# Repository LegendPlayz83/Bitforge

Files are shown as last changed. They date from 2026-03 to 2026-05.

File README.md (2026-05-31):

# Bitforge



Online view:


Features:

- 81x Diodes
- 81x keys
- Raspberry Pi Pico
- Customised layout
- QMK firmware
  
### Schematic


### PCB 


### Case


### BOM

| Name | Quantity | Cost | Link |
|---|---|---|---|
| TTC Silent Red V3 | 81 | $44.99 | [Buy](https://stackskb.com/store/ttc-silent-red-v3-switch/) |
| Durock Smokey Screw-In Stabilizers V2 (4+1 w/ 6.25u spacebar) | 1 | $17.01 | [Buy](https://stackskb.com/store/durock-smokey-screw-in-stabilizers-v2/) |
| Womier Azure Eclipse Side Backlit Cherry PBT Keycap | 1 | $26 | [Buy](https://curiositycaps.in/products/flow-backlit-side-printed-cherry-pbt-keycap-set) |
| Diode 1N4148 Through-Hole | 100 | $2.15 | [Buy](https://www.amazon.in/dp/B084ZP5BJ3) |
| PCB - (Black Color) | 5 | $60.00 | [Buy](https://jlcpcb.com/) |
| Raspberry Pi Pico | 1 | $6.40 | [Buy](https://www.amazon.in/Raspberry-Pi-Headers-Soldered-Micro/dp/B08WPNM7JB) |
| Heatset and Screws | 1 | $0.00 | Self-sourced |
| Case (top, mid, bot) | 1 | $0.00 | Printing Legion |
| **Total** | | **$158.99** | |

The total costs come out to be $159

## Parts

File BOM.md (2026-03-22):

### BOM

| Name | Quantity | Cost | Link |
|---|---|---|---|
| TTC Silent Red V3 | 81 | $47 | [Buy](https://stackskb.com/store/ttc-silent-red-v3-switch/) |
| Durock Smokey Screw-In Stabilizers V2 (4+1 w/ 6.25u spacebar) | 1 | $20 | [Buy](https://stackskb.com/store/durock-smokey-screw-in-stabilizers-v2/) |
| Womier Azure Eclipse Side Backlit Cherry PBT Keycap | 1 | $26 | [Buy](https://curiositycaps.in/products/flow-backlit-side-printed-cherry-pbt-keycap-set) |
| Diode 1N4148 Through-Hole | 100 | $2.15 | [Buy](https://www.amazon.in/dp/B084ZP5BJ3) |
| PCB - (Black Color) | 5 | $42.00 | [Buy](https://jlcpcb.com/) |
| Raspberry Pi Pico | 1 | $10 | [Buy](https://www.amazon.in/Raspberry-Pi-Headers-Soldered-Micro/dp/B08WPNM7JB) |
| Heatset and Screws | 1 | $6 | [Buy](https://www.onlyscrews.in)  |
| Case  | 1 | $5.00 | Printing Legion |
| **Total** | | **$158.15** | |

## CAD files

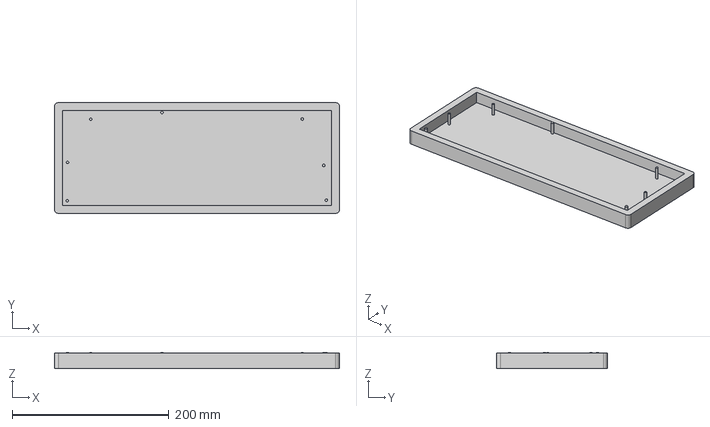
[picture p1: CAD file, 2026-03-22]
CAD/Bitforge-Case.step
363.4 x 141.4 x 20.6 mm

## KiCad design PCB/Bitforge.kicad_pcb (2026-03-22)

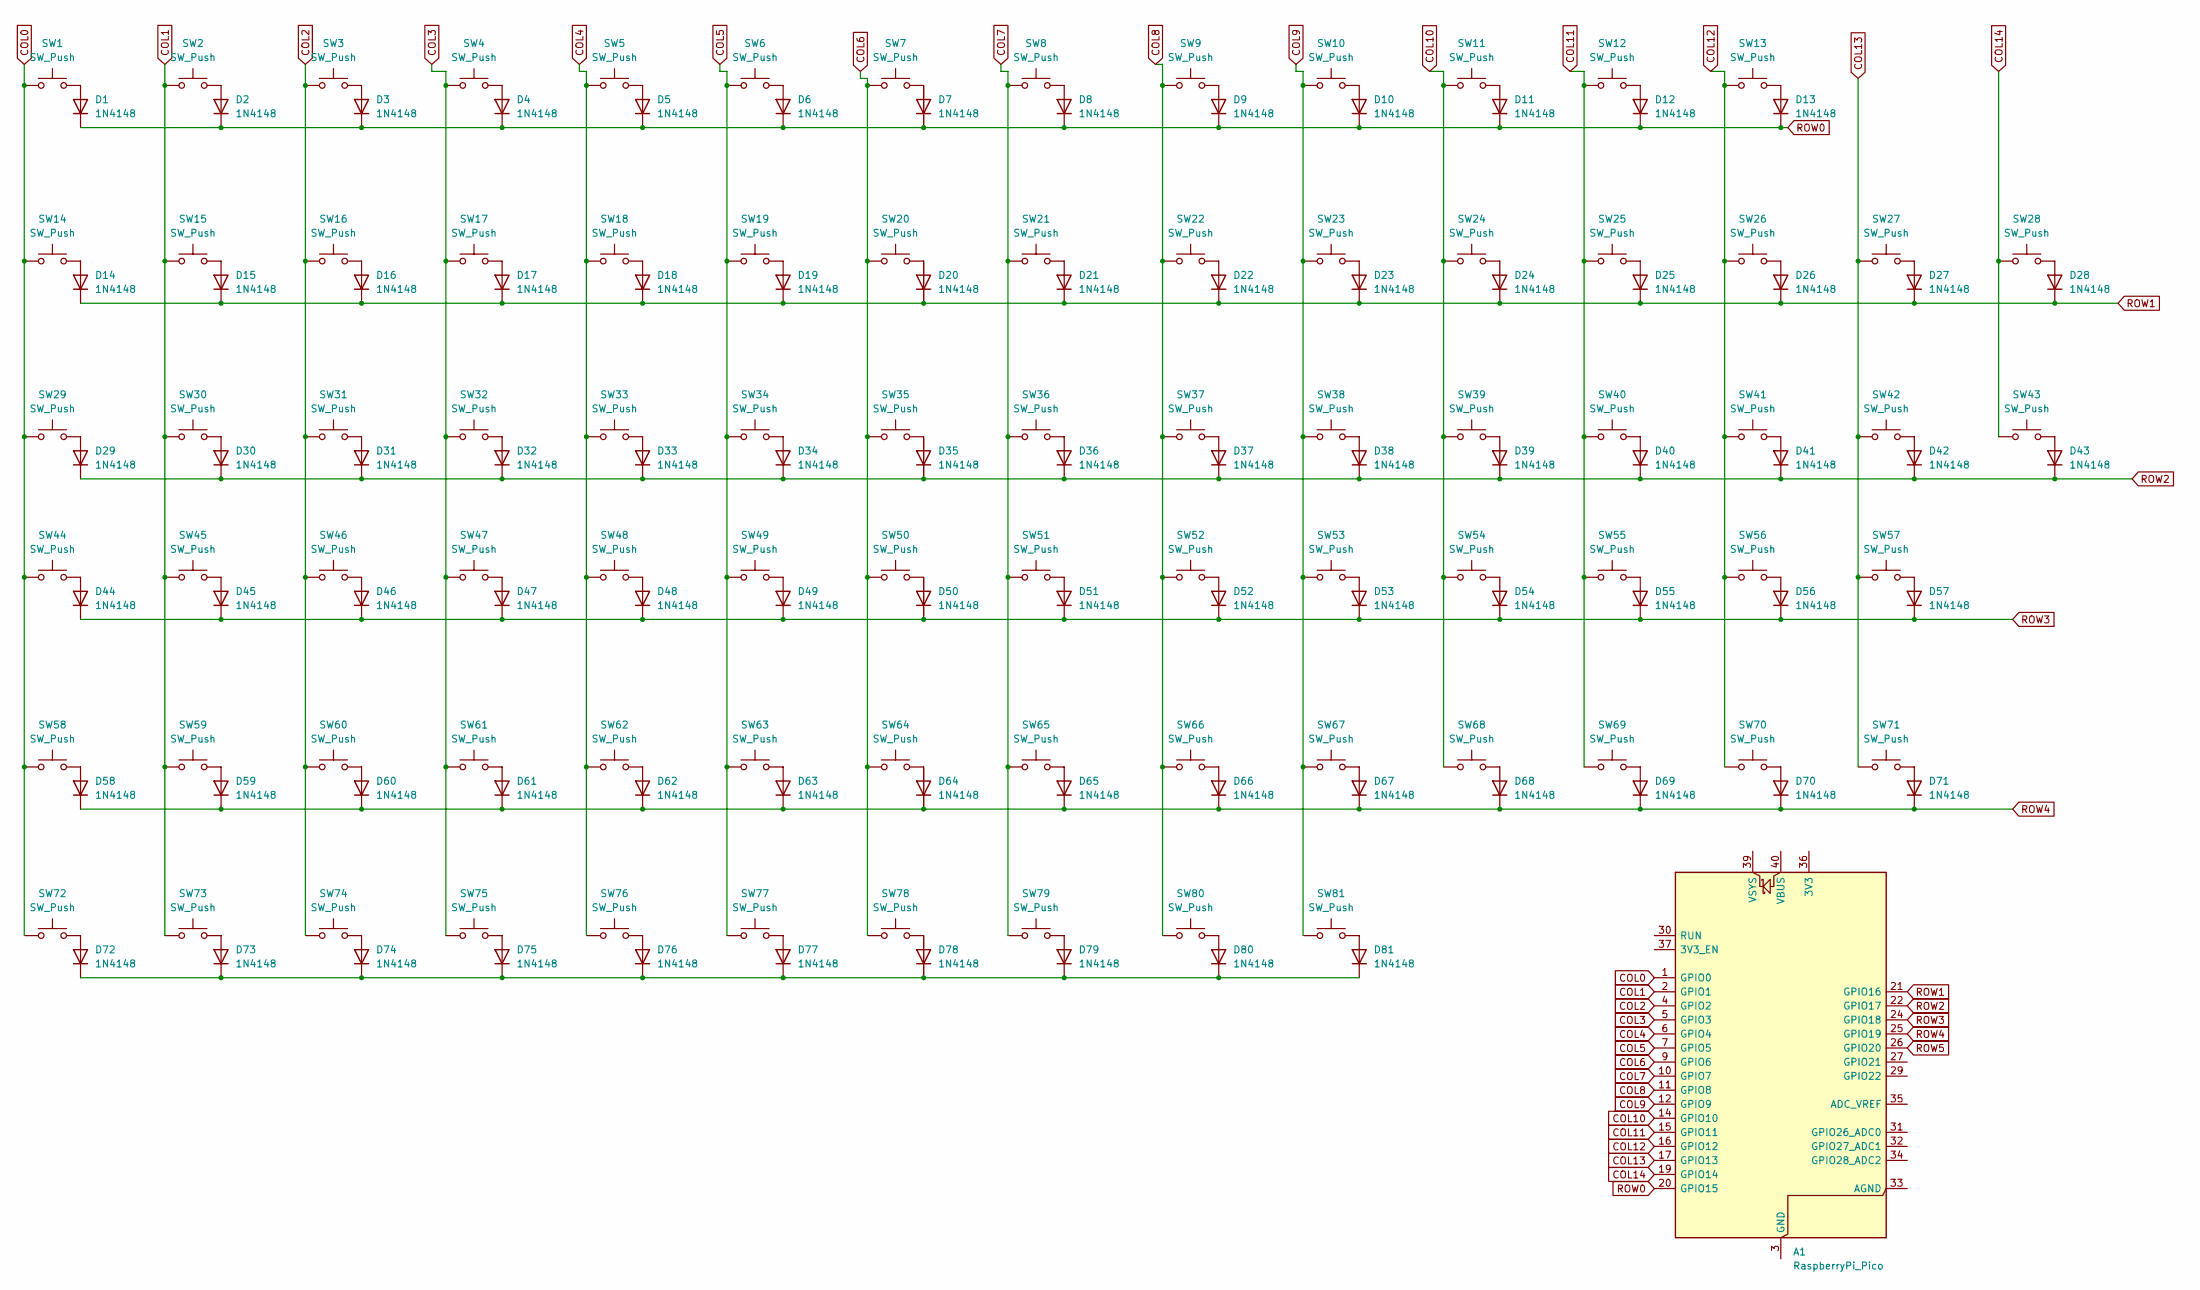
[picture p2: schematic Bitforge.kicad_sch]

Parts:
A1: RaspberryPi_Pico; RaspberryPi_Pico_Common_THT
D1, D2, D3, D4, D5, D6, D7, D8, D9, D10, D11, D12, D13, D14, D15, D16, D17, D18, D19, D20, D21, D22, D23, D24, D25, D26, D27, D28, D29, D30, D31, D32, D33, D34, D35, D36, D37, D38, D39, D40, D41, D42, D43, D44, D45, D46, D47, D48, D49, D50, D51, D52, D53, D54, D55, D56, D57, D58, D59, D60, D61, D62, D63, D64, D65, D66, D67, D68, D69, D70, D71, D72, D73, D74, D75, D76, D77, D78, D79, D80, D81: 1N4148; D_DO-35_SOD27_P7.62mm_Horizontal
SW1, SW2, SW3, SW4, SW5, SW6, SW7, SW8, SW9, SW10, SW11, SW12, SW13, SW14, SW15, SW16, SW17, SW18, SW19, SW20, SW21, SW22, SW23, SW24, SW25, SW26, SW28, SW30, SW31, SW32, SW33, SW34, SW35, SW36, SW37, SW38, SW39, SW40, SW41, SW43, SW45, SW46, SW47, SW48, SW49, SW50, SW51, SW52, SW53, SW54, SW55, SW57, SW59, SW60, SW61, SW62, SW63, SW64, SW65, SW66, SW67, SW68, SW70, SW71, SW76, SW77, SW78, SW79, SW80, SW81: SW_Push; SW_Cherry_MX_1.00u_PCB
SW27: SW_Push; SW_Cherry_MX_2.00u_PCB
SW29: SW_Push; SW_Cherry_MX_1.50u_PCB
SW42, SW72, SW73, SW74: SW_Push; SW_Cherry_MX_1.25u_PCB
SW44, SW69: SW_Push; SW_Cherry_MX_1.75u_PCB
SW56, SW58: SW_Push; SW_Cherry_MX_2.25u_PCB
SW75: SW_Push; SW_Cherry_MX_6.25u_PCB

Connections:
COL0: A1.1 (GPIO0), SW1.1, SW14.1, SW29.1, SW44.1, SW58.1, SW72.1
COL1: A1.2 (GPIO1), SW2.1, SW15.1, SW30.1, SW45.1, SW59.1, SW73.1
COL2: A1.4 (GPIO2), SW3.1, SW16.1, SW31.1, SW46.1, SW60.1, SW74.1
COL3: A1.5 (GPIO3), SW4.1, SW17.1, SW32.1, SW47.1, SW61.1, SW75.1
COL4: A1.6 (GPIO4), SW5.1, SW18.1, SW33.1, SW48.1, SW62.1, SW76.1
COL5: A1.7 (GPIO5), SW6.1, SW19.1, SW34.1, SW49.1, SW63.1, SW77.1
COL6: A1.9 (GPIO6), SW7.1, SW20.1, SW35.1, SW50.1, SW64.1, SW78.1
COL7: A1.10 (GPIO7), SW8.1, SW21.1, SW36.1, SW51.1, SW65.1, SW79.1
COL8: A1.11 (GPIO8), SW9.1, SW22.1, SW37.1, SW52.1, SW66.1, SW80.1
COL9: A1.12 (GPIO9), SW10.1, SW23.1, SW38.1, SW53.1, SW67.1, SW81.1
COL10: A1.14 (GPIO10), SW11.1, SW24.1, SW39.1, SW54.1, SW68.1
COL11: A1.15 (GPIO11), SW12.1, SW25.1, SW40.1, SW55.1, SW69.1
COL12: A1.16 (GPIO12), SW13.1, SW26.1, SW41.1, SW56.1, SW70.1
COL13: A1.17 (GPIO13), SW27.1, SW42.1, SW57.1, SW71.1
COL14: A1.19 (GPIO14), SW28.1, SW43.1
unnamed: A1.3 (GND), A1.8 (GND), A1.13 (GND), A1.18 (GND), A1.23 (GND), A1.28 (GND), A1.38 (GND)
unnamed: D1.2 (A), SW1.2
unnamed: D2.2 (A), SW2.2
unnamed: D3.2 (A), SW3.2
unnamed: D4.2 (A), SW4.2
unnamed: D5.2 (A), SW5.2
unnamed: D6.2 (A), SW6.2
unnamed: D7.2 (A), SW7.2
unnamed: D8.2 (A), SW8.2
unnamed: D9.2 (A), SW9.2
unnamed: D10.2 (A), SW10.2
unnamed: D11.2 (A), SW11.2
unnamed: D12.2 (A), SW12.2
unnamed: D13.2 (A), SW13.2
unnamed: D14.2 (A), SW14.2
unnamed: D15.2 (A), SW15.2
unnamed: D16.2 (A), SW16.2
unnamed: D17.2 (A), SW17.2
unnamed: D18.2 (A), SW18.2
unnamed: D19.2 (A), SW19.2
unnamed: D20.2 (A), SW20.2
unnamed: D21.2 (A), SW21.2
unnamed: D22.2 (A), SW22.2
unnamed: D23.2 (A), SW23.2
unnamed: D24.2 (A), SW24.2
unnamed: D25.2 (A), SW25.2
unnamed: D26.2 (A), SW26.2
unnamed: D27.2 (A), SW27.2
unnamed: D28.2 (A), SW28.2
unnamed: D29.2 (A), SW29.2
unnamed: D30.2 (A), SW30.2
unnamed: D31.2 (A), SW31.2
unnamed: D32.2 (A), SW32.2
unnamed: D33.2 (A), SW33.2
unnamed: D34.2 (A), SW34.2
unnamed: D35.2 (A), SW35.2
unnamed: D36.2 (A), SW36.2
unnamed: D37.2 (A), SW37.2
unnamed: D38.2 (A), SW38.2
unnamed: D39.2 (A), SW39.2
unnamed: D40.2 (A), SW40.2
unnamed: D41.2 (A), SW41.2
unnamed: D42.2 (A), SW42.2
unnamed: D43.2 (A), SW43.2
unnamed: D44.2 (A), SW44.2
unnamed: D45.2 (A), SW45.2
unnamed: D46.2 (A), SW46.2
unnamed: D47.2 (A), SW47.2
unnamed: D48.2 (A), SW48.2
unnamed: D49.2 (A), SW49.2
unnamed: D50.2 (A), SW50.2
unnamed: D51.2 (A), SW51.2
unnamed: D52.2 (A), SW52.2
unnamed: D53.2 (A), SW53.2
unnamed: D54.2 (A), SW54.2
unnamed: D55.2 (A), SW55.2
unnamed: D56.2 (A), SW56.2
unnamed: D57.2 (A), SW57.2
unnamed: D58.2 (A), SW58.2
unnamed: D59.2 (A), SW59.2
unnamed: D60.2 (A), SW60.2
unnamed: D61.2 (A), SW61.2
unnamed: D62.2 (A), SW62.2
unnamed: D63.2 (A), SW63.2
unnamed: D64.2 (A), SW64.2
unnamed: D65.2 (A), SW65.2
unnamed: D66.2 (A), SW66.2
unnamed: D67.2 (A), SW67.2
unnamed: D68.2 (A), SW68.2
unnamed: D69.2 (A), SW69.2
unnamed: D70.2 (A), SW70.2
unnamed: D71.2 (A), SW71.2
unnamed: D72.2 (A), SW72.2
unnamed: D72.1 (K), D73.1 (K), D74.1 (K), D75.1 (K), D76.1 (K), D77.1 (K), D78.1 (K), D79.1 (K), D80.1 (K), D81.1 (K)
unnamed: D73.2 (A), SW73.2
unnamed: D74.2 (A), SW74.2
unnamed: D75.2 (A), SW75.2
unnamed: D76.2 (A), SW76.2
unnamed: D77.2 (A), SW77.2
unnamed: D78.2 (A), SW78.2
unnamed: D79.2 (A), SW79.2
unnamed: D80.2 (A), SW80.2
unnamed: D81.2 (A), SW81.2
ROW0: A1.20 (GPIO15), D1.1 (K), D2.1 (K), D3.1 (K), D4.1 (K), D5.1 (K), D6.1 (K), D7.1 (K), D8.1 (K), D9.1 (K), D10.1 (K), D11.1 (K), D12.1 (K), D13.1 (K)
ROW1: A1.21 (GPIO16), D14.1 (K), D15.1 (K), D16.1 (K), D17.1 (K), D18.1 (K), D19.1 (K), D20.1 (K), D21.1 (K), D22.1 (K), D23.1 (K), D24.1 (K), D25.1 (K), D26.1 (K), D27.1 (K), D28.1 (K)
ROW2: A1.22 (GPIO17), D29.1 (K), D30.1 (K), D31.1 (K), D32.1 (K), D33.1 (K), D34.1 (K), D35.1 (K), D36.1 (K), D37.1 (K), D38.1 (K), D39.1 (K), D40.1 (K), D41.1 (K), D42.1 (K), D43.1 (K)
ROW3: A1.24 (GPIO18), D44.1 (K), D45.1 (K), D46.1 (K), D47.1 (K), D48.1 (K), D49.1 (K), D50.1 (K), D51.1 (K), D52.1 (K), D53.1 (K), D54.1 (K), D55.1 (K), D56.1 (K), D57.1 (K)
ROW4: A1.25 (GPIO19), D58.1 (K), D59.1 (K), D60.1 (K), D61.1 (K), D62.1 (K), D63.1 (K), D64.1 (K), D65.1 (K), D66.1 (K), D67.1 (K), D68.1 (K), D69.1 (K), D70.1 (K), D71.1 (K)
ROW5: A1.26 (GPIO20)

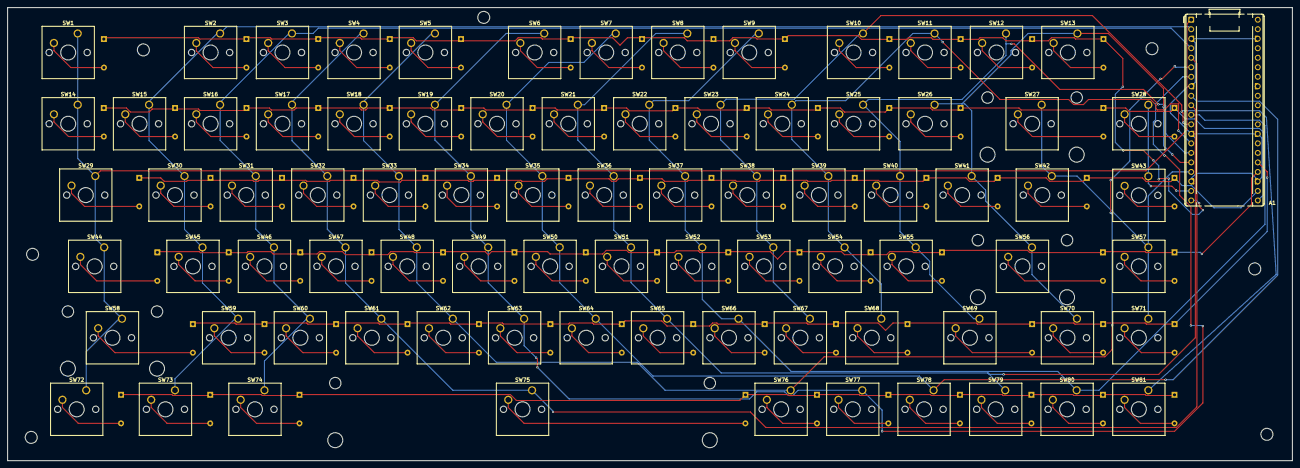
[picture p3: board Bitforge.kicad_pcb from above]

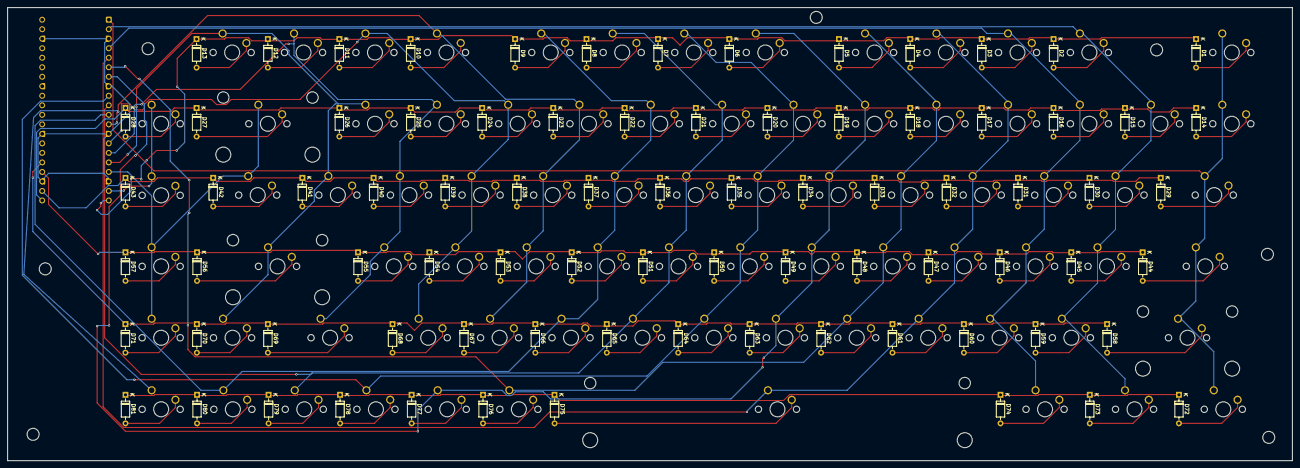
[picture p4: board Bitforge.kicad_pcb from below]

Board: 2 copper layers, 343.0 x 121.0 mm, 163 parts (81 on the bottom side), 103 nets.

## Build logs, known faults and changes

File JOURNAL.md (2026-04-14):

<h1>Journal</h1>
Title: "BitForge"<br>
Author: "Aditya Roy(U04AKUFC402)"<br>
Description: "A 80% Keyboard made from scratch in KiCad and Fusion360"<br>

<h3>Physical assembly time!</h3>
After getting all the components, I started by placing the diodes in place. In this, I had to bend each side of the diode to sit exactly in the centre of the logo, else it would have gone left or right while soldering.




Time taken: 3.2hours
<b>Total Time: 3.2Hours</b>

<h4>Placed Stabs and soldered keys with Ras Pi pico</h4>
After placing and soldering all of the 1N4148 diodes, I now had to solder my Cherry MX keys to the PCB. This was done in 2-3 days in different sessions so you can see the progress






Time taken: 4 hours
<b>Total time: 7.2 hours</b>

<h3>Firmware time!!!</h3>
After being done with the soldering and things, I now had to upload the code to the Pico. I made many versions of the code coz the keys acted weird, rows and columns were wrongly arranged, and there were many bugs with the code.


Time taken: 6.6 hours
<b>Total time: 13.8 hours</b>


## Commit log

2026-03-22 Update and rename README.md to BOM.md
2026-03-22 Add initial README for Bitforge project
    Added detailed information about the Bitforge project, including features, schematic, PCB, case images, and BOM.
2026-03-22 Revise BOM with updated prices and links
    Updated component costs and links in the BOM.
2026-04-14 Add journal entry for BitForge keyboard assembly
    Documented the process of building the BitForge keyboard, including assembly, soldering, and firmware uploading with time logs.
